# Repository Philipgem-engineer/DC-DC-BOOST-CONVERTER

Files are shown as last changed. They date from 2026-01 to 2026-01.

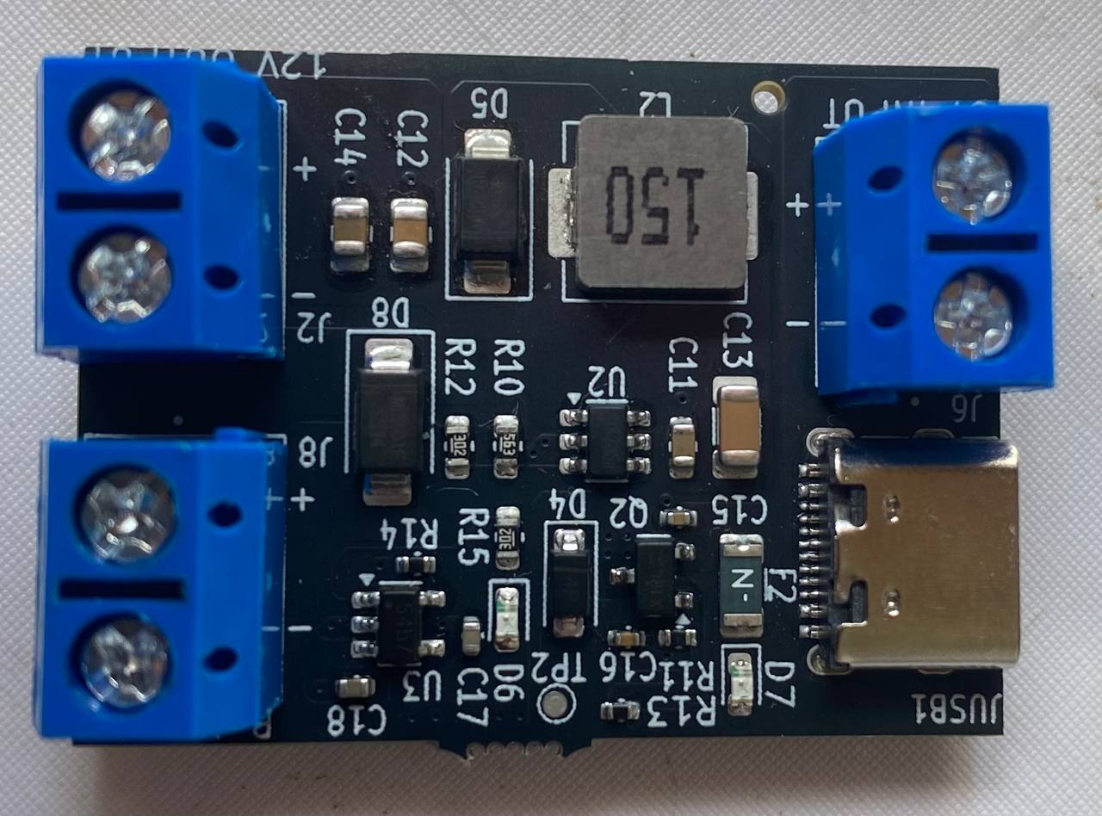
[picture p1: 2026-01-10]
DC-DC Boost Converter/Media/DC-DC-BOOST-CONVERTER.jpg

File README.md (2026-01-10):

# DC-DC-BOOST-CONVERTER
This repository contains schematic and PCB design of a DC DC BOOST CONVERTER that steps up voltage from 5 V to 12 V. It also contains battery charging circuit.

##  FEATURES
 - INPUT VOLTAGE: 5 V
 - OUTPUT VOLTAGE: 12 V
 - OUTPUT CURRENT: 4 A
 - 97% Efficiency
 - under-voltage lockout, current limiting, and thermal overload protection to prevent damage in the event of an output overload

##  TOOLS USED:
 - Schematic & PCB Design: KiCad
 - Component Library: LCSC
 - PCB Fabrication: JLCPCB

##  SCHEMATIC



##  PCB


##  PCB 3D VIEW



##  MANUFACTURED PCB
DC-DC Boost Converter

## 📁 File Structure

<details>
  <summary>DC-DC Boost Converter</summary>
  <ul>
    <li>
      Media/
      <ul>
        <li>(PDF, images, and videos of prototype)</li>
      </ul>
    </li>
    <li>
      Production Files/
      <ul>
        <li>(Gerber, BOM, positions)</li>
      </ul>
    </li>
    <li>
      KiCad Files/
      <ul>
        <li>(Schematic, PCB, library)</li>
      </ul>
    </li>
  </ul>
</details>

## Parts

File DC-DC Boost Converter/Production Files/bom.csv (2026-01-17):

Designator | Footprint | Quantity | Value | LCSC Part #
C11 | 0603 | 1 | 22 uF | C59461
C12, C14 | 0805 | 2 | 22 uF | C45783
C13 | 1206 | 1 | 100 uF | C15008
C15 | 0402 | 1 | 100 nF | C1525
C16 | 0402 | 1 | 4.7 nF | C1538
C17, C18 | 0402 | 2 | 10uF | C15525
D4 | D_SOD-123 | 1 | D_Zener | C22395539
D5 | D_SMA | 1 | SS34 | C8678
D6, D7 | 0603 | 2 | LED | C2286
D8 | D_SMA | 1 | SS14 | C2480
F2 | 1206 | 1 | Polyfuse_Small | C207041
J2, J6, J8 | HANDSON_KF301-2P | 3 | KF301-2P
JUSB1 | USB_TYPE_18 | 1 | ~ | C2927038
L2 | L_APV_APH0630 | 1 | 15 uH | C5349699
Q2 | SOT-23 | 1 | AO3401A | C15127
R10 | 0603 | 1 | 56 KΩ | C23206
R11 | 0402 | 1 | 100K | C25741
R12, R15 | 0603 | 2 | 3 KΩ | C4211
R13 | 0402 | 1 | 1 KΩ | C11702
R14 | 0402 | 1 | 2K | C4109
TP2 | TestPoint_Pad_D1.0mm | 1 | TestPoint
U2 | SOT-23-6 | 1 | MT3608 | C84817
U3 | SOT-23-5 | 1 | ~ | C32574

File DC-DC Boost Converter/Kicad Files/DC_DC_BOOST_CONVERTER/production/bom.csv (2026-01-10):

Designator | Footprint | Quantity | Value | LCSC Part #
C1 | 402 | 1 | 10 nF | C15195
C10 | 603 | 1 | 150 pF | C1594
C11, C5 | 603 | 2 | 22 uF | C59461
C12, C14 | 805 | 2 | 22 uF | C45783
C13, C3, C4 | 1206 | 3 | 100 uF | C15008
C15, C6, C9 | 402 | 3 | 100 nF | C1525
C16, C7 | 402 | 2 | 4.7 nF | C1538
C17, C18 | 402 | 2 | 10uF | C15525
C2 | 805 | 1 | 10 uF | C15850
C8 | 603 | 1 | 1.5 nF | C1595
D1, D5 | D_SMA | 2 | SS34 | C8678
D2, D6, D7 | 603 | 3 | LED | C2286
D3, D4 | D_SOD-123 | 2 | D_Zener | C22395539
D8 | D_SMA | 1 | SS14 | C2480
F1, F2 | 1206 | 2 | Polyfuse_Small | C207041
J1, J2, J3, J6, J8 | HANDSON_KF301-2P | 5 | KF301-2P | DNP
J4 | USB_A_Molex_67643_Horizontal | 1 | USB_A | DNP
J5 | NINIGI_DC-005 | 1 | DC-005 | DNP
JUSB1 | USB_TYPE_18 | 1 | ~ | C2927038
L1, L2 | L_APV_APH0630 | 2 | 15 uH | C5349699
Q1, Q2 | SOT-23 | 2 | AO3401A | C15127
R1, R5 | 402 | 2 | 10 KΩ | C25744
R10 | 603 | 1 | 56 KΩ | C23206
R11, R4 | 402 | 2 | 100K | C25741
R12, R15 | 603 | 2 | 3 KΩ | C4211
R13, R6 | 402 | 2 | 1 KΩ | C11702
R14 | 402 | 1 | 2K | C4109
R2 | 402 | 1 | 3.24 KΩ | C25890
R3 | 1206 | 1 | 100 mΩ | C25334
R7 | 603 | 1 | 5.6 KΩ | C23189
R8 | 603 | 1 | 300 Ω | C23025
R9 | 603 | 1 | 560 Ω | C23204
U1 | TI_SO-PowerPAD-8_ThermalVias | 1 | TPS5430DDA | C9864
U2 | MT3608 | 1 | MT3608 | C84817
U3 | TP4054-42-SOT25R | 1 | TP4054-42-SOT25R | C32574

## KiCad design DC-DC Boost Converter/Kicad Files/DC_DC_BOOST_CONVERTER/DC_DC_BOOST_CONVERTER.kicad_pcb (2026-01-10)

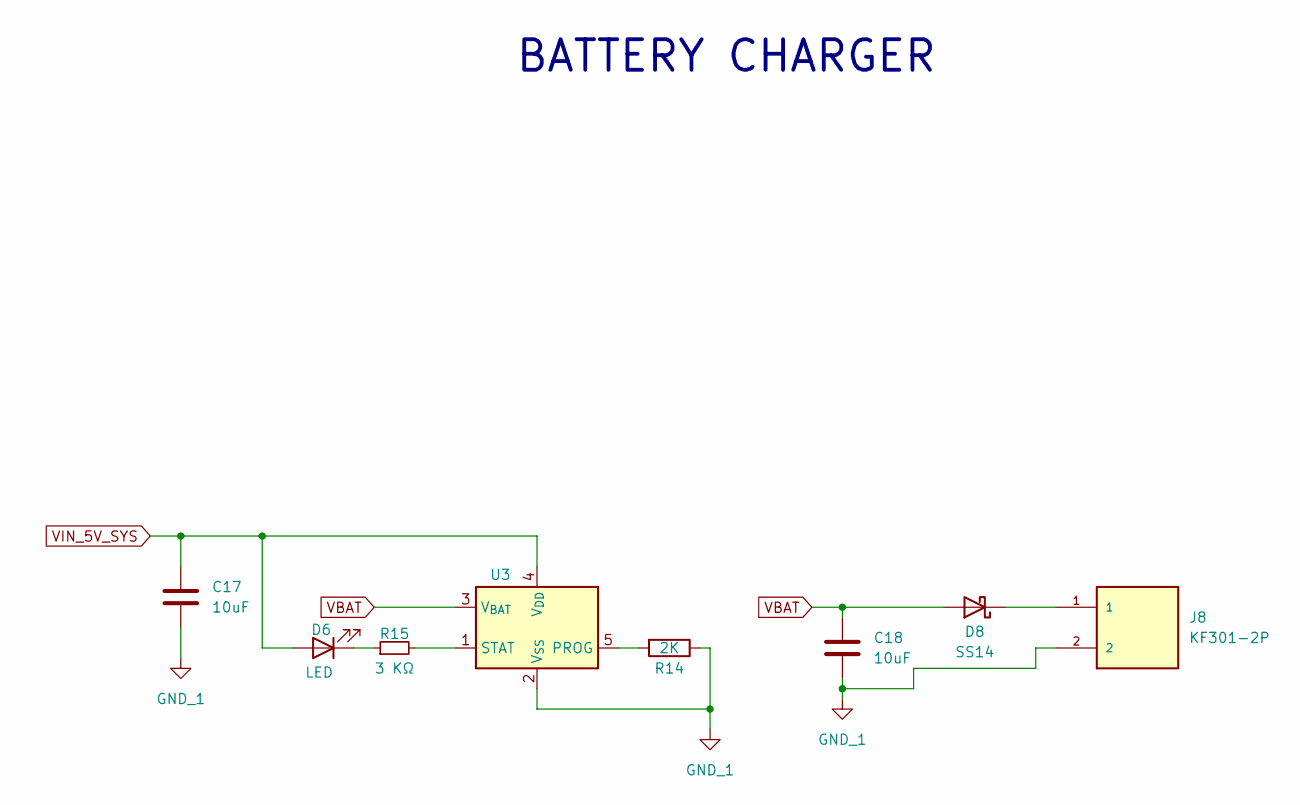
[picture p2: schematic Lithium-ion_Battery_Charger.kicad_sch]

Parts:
C17, C18: 10uF; C_0402_1005Metric; MNF PART NUMBER C15525; LCSC C15525
D6: LED; LED_0603_1608Metric; MNF PART NUMBER C2286; LCSC C2286
D8: SS14; D_SMA; MNF PART NUMBER C2480; LCSC C2480
J8: KF301-2P; HANDSON_KF301-2P; PARTREV NA
R14: 2K; R_0402_1005Metric; MNF PART NUMBER C4109; LCSC C4109
R15: 3 KΩ; C_0603_1608Metric; MPN 0603WAF3001T5E; LCSC PN C4211
U3: SOT-23-5; MPN TP4054-42-SOT25R; LCSC PN C32574

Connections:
GND_1: C17.2, C18.2, J8.2, R14.1, U3.2 (V_{SS}); also elsewhere on the board
unnamed: D6.1 (K), R15.1
unnamed: D8.1 (K), J8.1
unnamed: R14.2, U3.5 (PROG)
unnamed: R15.2, U3.1 (STAT)
VBAT: C18.1, D8.2 (A), U3.3 (V_{BAT})
VIN_5V_SYS: C17.1, D6.2 (A), U3.4 (V_{DD}); also elsewhere on the board

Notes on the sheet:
BATTERY CHARGER

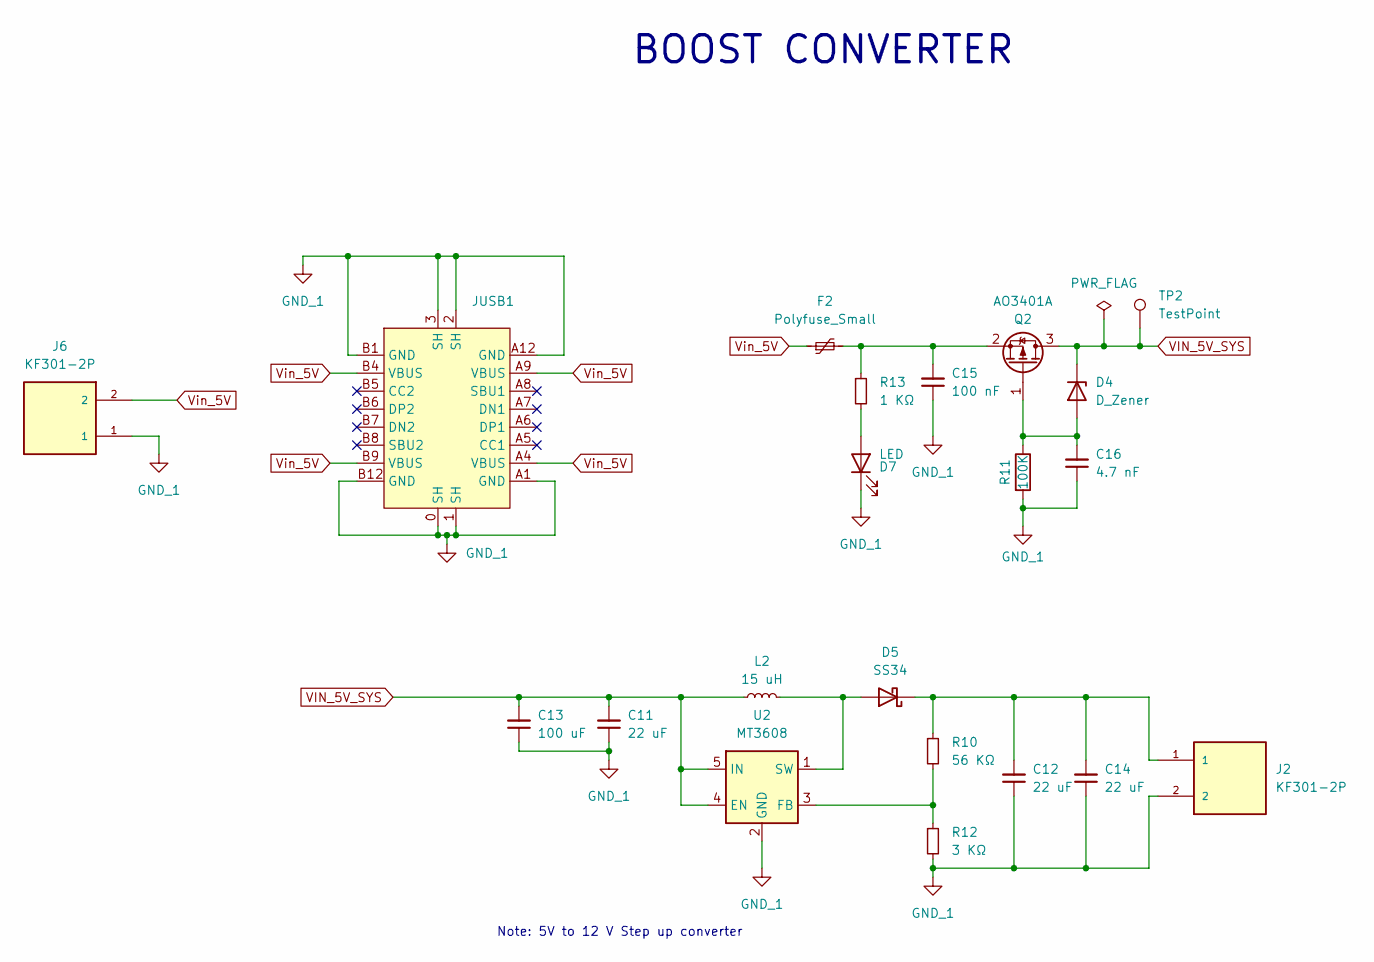
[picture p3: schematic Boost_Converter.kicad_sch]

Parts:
C11: 22 uF; C_0603_1608Metric; MPN CL10A226MQ8NRNC; LCSC PN C59461
C12, C14: 22 uF; C_0805_2012Metric; MPN CL21A226MAQNNNE; LCSC PN C45783
C13: 100 uF; C_1206_3216Metric; MPN CL31A107MQHNNNE; LCSC PN C15008
C15: 100 nF; C_0402_1005Metric; MPN CL05B103KB5NNNC; LCSC PN C1525
C16: 4.7 nF; C_0402_1005Metric; MPN 0402B472K500NT; LCSC PN C1538
D4: D_Zener; D_SOD-123; MPN MM1Z5V6; LCSC PN C22395539
D5: SS34; D_SMA; MPN SS34; LCSC PN C8678
D7: LED; LED_0603_1608Metric; MNF PART NUMBER C2286; LCSC C2286
F2: Polyfuse_Small; Fuse_1206_3216Metric; MPN 1206L300SLTHYR; LCSC PN C207041
J2, J6: KF301-2P; HANDSON_KF301-2P; PARTREV NA
JUSB1: USB_TYPE_18; MPN USB-TYPE-C-018; LCSC PN C2927038
L2: 15 uH; L_APV_APH0630; MPN APH0630T150M; LCSC PN C5349699
Q2: AO3401A; SOT-23; MNF PART NUMBER C15127; LCSC C15127
R10: 56 KΩ; C_0603_1608Metric; MPN 0603WAF5602T5E; LCSC PN C23206
R11: 100K; R_0402_1005Metric; MNF PART NUMBER C25741; LCSC C25741
R12: 3 KΩ; C_0603_1608Metric; MPN 0603WAF3001T5E; LCSC PN C4211
R13: 1 KΩ; R_0402_1005Metric; MPN 0402WGF1001TCE; LCSC PN C11702
TP2: TestPoint; TestPoint_Pad_D1.0mm
U2: MT3608; SOT-23-6; MPN MT3608; LCSC PN C84817

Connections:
GND_1: C11.1, C12.1, C13.1, C14.1, C15.1, C16.1, D7.1 (K), J2.2, J6.1, JUSB1.0 (SH), JUSB1.1 (SH), JUSB1.2 (SH), JUSB1.3 (SH), JUSB1.A1 (GND), JUSB1.A12 (GND), JUSB1.B1 (GND), JUSB1.B12 (GND), R11.2, R12.2, U2.2 (GND); also elsewhere on the board
unnamed: C16.2, D4.2 (A), Q2.1 (G), R11.1
unnamed: D5.2 (A), L2.2, U2.1 (SW)
unnamed: C12.2, C14.2, D5.1 (K), J2.1, R10.1
unnamed: D7.2 (A), R13.2
unnamed: C15.2, F2.2, Q2.2 (S), R13.1
unnamed: R10.2, R12.1, U2.3 (FB)
VIN_5V_SYS: C11.2, C13.2, D4.1 (K), L2.1, Q2.3 (D), TP2.1, U2.4 (EN), U2.5 (IN); also elsewhere on the board
Vin_5V: F2.1, J6.2, JUSB1.A4 (VBUS), JUSB1.A9 (VBUS), JUSB1.B4 (VBUS), JUSB1.B9 (VBUS)

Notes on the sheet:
BOOST CONVERTER
Note: 5V to 12 V Step up converter

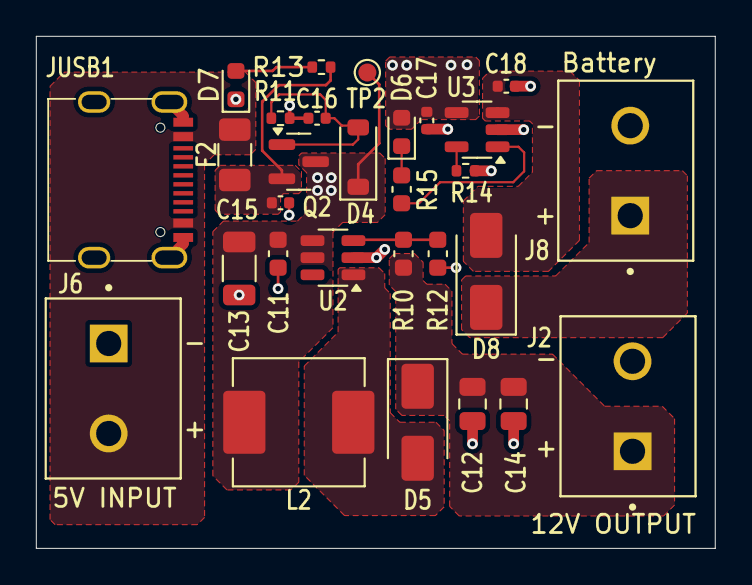
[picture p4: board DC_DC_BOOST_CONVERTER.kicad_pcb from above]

Board: 2 copper layers, 37.7 x 28.4 mm, 29 parts (0 on the bottom side), 14 nets.
